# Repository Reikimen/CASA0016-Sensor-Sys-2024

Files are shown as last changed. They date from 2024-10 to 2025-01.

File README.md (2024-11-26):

---
typora-root-url: ./
---

# CASA-0016 Individual Coursework

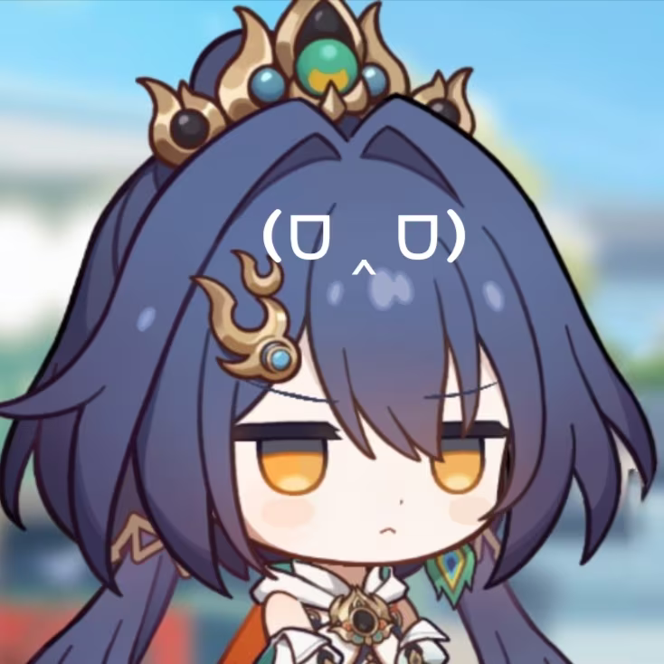
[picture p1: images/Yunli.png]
 Dankao Chen

In today's world of increasing air pollution, fresh air is no longer something to be taken for granted, but an important part of our quest for a healthy life. The completion of this project “Pure-Breath” is my personal attempt to combine technological innovation with healthy living (within module CASA-0016 ). I would like to express my special thanks to Prof. Martin for his careful guidance and valuable advice during the development process, which helped me to turn this idea into a real product.

I hope this project will not only improve the indoor air quality and living experience, but also inspire more people to become interested in the integration of technology and the environment! https://github.com/Reikimen/CASA0016-Sensor-Sys-2024

# Intro

This project designs and implements an air purification device called “Pure-Breath”. The device is based on the ESP8266 development board and provides real-time interaction, air quality monitoring, temperature and humidity display, fan control and other functions by integrating various sensors and modules. The device aims to improve indoor air quality and help users identify and respond to possible air pollution problems.

## P1 Causes of Respiratory Hypersensitiy

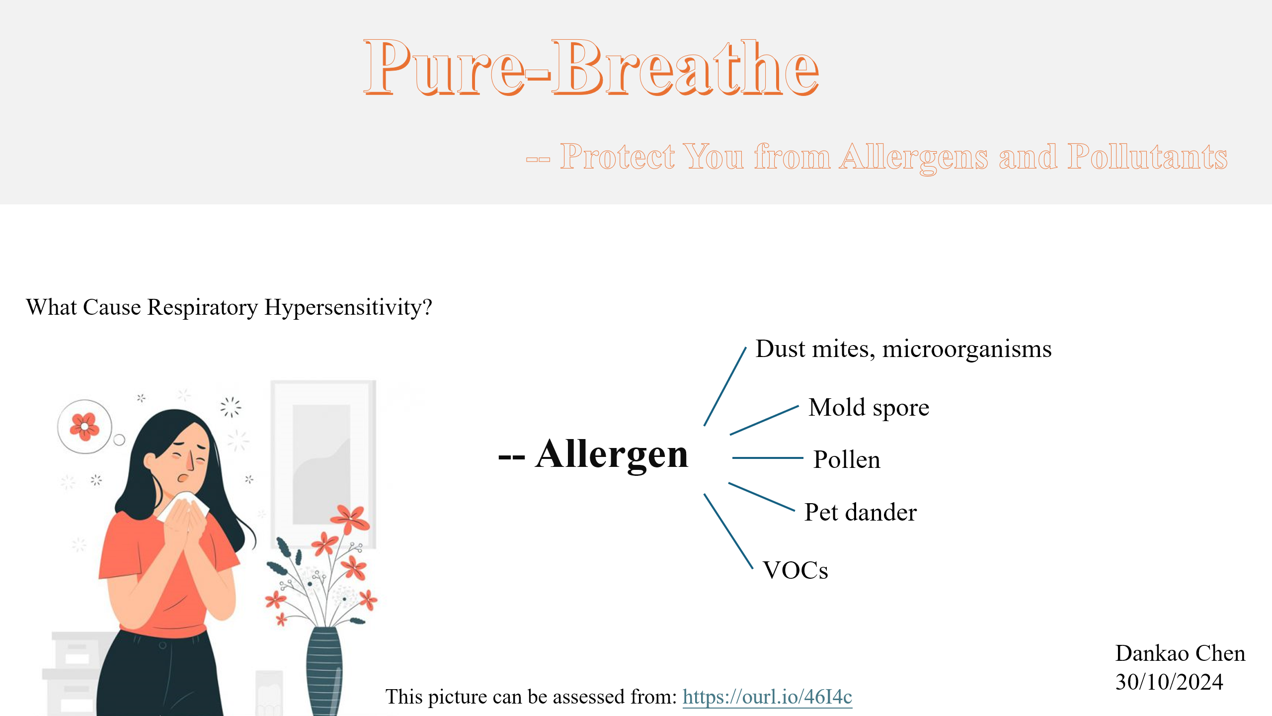
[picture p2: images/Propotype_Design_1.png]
Propotype_Design_1


## P2 Three Basic Functions of "Pure-Breath"

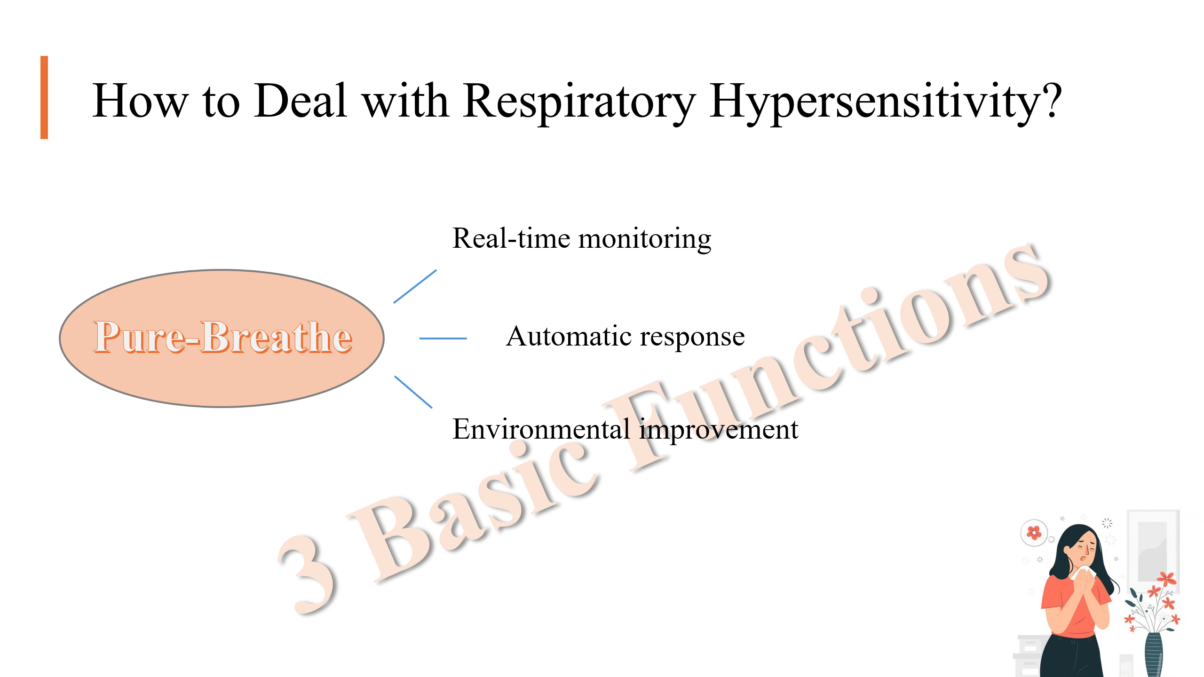
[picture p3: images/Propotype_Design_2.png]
Propotype_Design_2


## P3 The Prototype Design of "Pure-Breath"

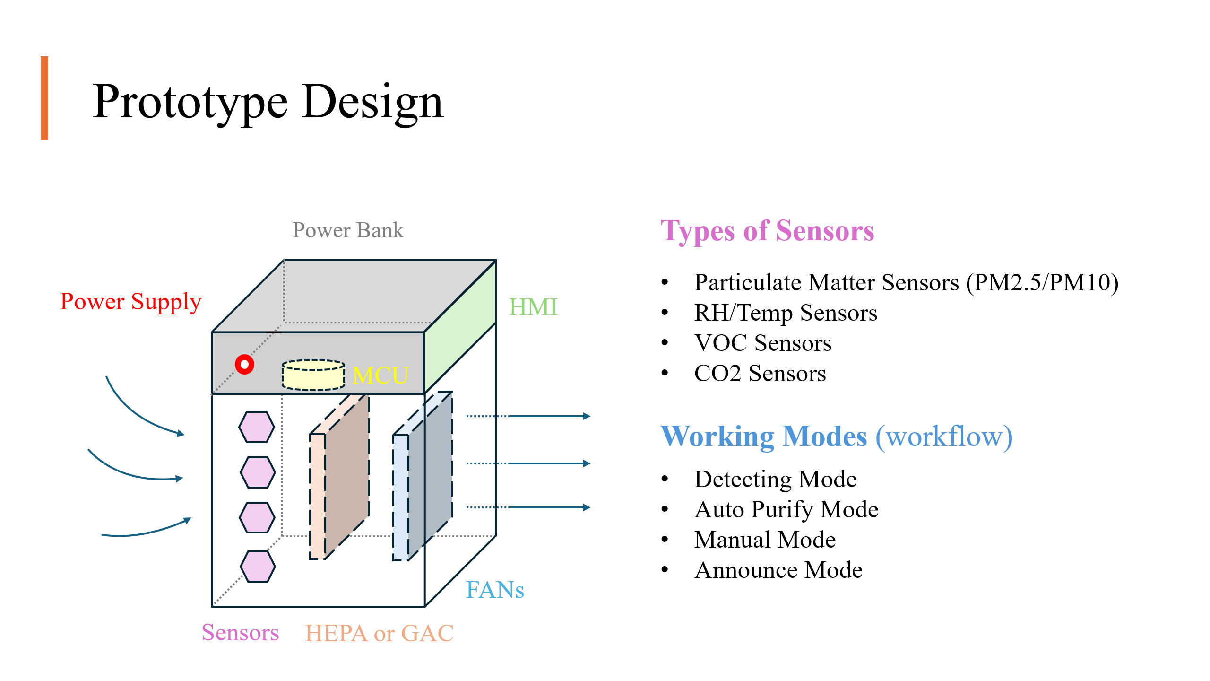
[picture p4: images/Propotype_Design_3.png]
Propotype_Design_3


However, the work flow or usage of this prototype design was not that detailed.

## P4 Product Prototype Showcase

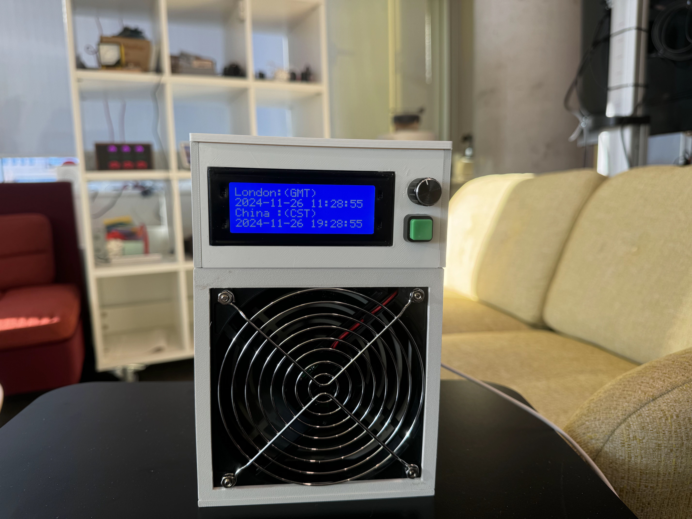
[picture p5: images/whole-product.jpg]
whole-product


<video src="/images/test.mp4" width="760" controls></video>

### Equipment features

1. **Air quality monitoring:**
   
   - Utilizes sensors (e.g. CCS811, MQ135, PMS7003) to monitor the environment in real time
   - including CO₂ concentration, TVOC value, and PM1.0, PM2.5 and PM10 particulate matter concentration.
2. **Temperature and humidity detection:**
   
   - Use SHT30 sensor to provide accurate ambient temperature and humidity data.
3. **Multi-mode fan control:**
   
   - Provides three fan modes: auto, on and off to adapt to different needs.
4. **World Time Display:**
   
   - Support synchronized display of London time and Beijing time, realized based on NTP protocol.
5. **Real-Time Interaction:**
	
	- Support 50ms interaction with users
6. **Flexible Power Supply:**
	
	- The power can be supplied both External power (e.g. Type-C) and Built-in Li-Ion battery
7. **Easy User Interaction:**
   
   - Equipped with rotary encoder and keys to support users easily and quickly switch modes and adjust settings.

### Technical characteristics

1. **Modularized design:**
   - The project is divided into several modules, including sensors, control logic, Wi-Fi connection, LCD display, etc.
   - Each module is developed independently to ensure that the system is easy to expand and maintain.
2. **Non-blocking Architecture:**
   
   - Use thread timer (RITOS method) instead of the traditional blocking delay (delay) to achieve efficient collaboration among modules.
3. **Double-buffered display:**
   
   - The use of LCD2004 screen, combined with double buffer technology, reduces I2C communication delay and improves display refresh efficiency (20HZ).
4. **High-Efficiency User Interaction:**

	- Integrates hardware (rotary encoder and buttons) and software optimization to ensure a smooth user experience without blocking system operations.

### Hardware Composition

- **Main controller chip:** ESP8266, responsible for overall logic control, Wi-Fi connection and data processing.
- **Sensors**:
  - MQ135: Monitor CO₂ concentration.
  - CCS811: Acquire eCO₂ and eTVOC data.
  - PMS7003: Detects PM particulate matter concentration.
  - SHT30: Provides ambient temperature and humidity data.
- **Display Module:** LCD2004, display sensor data and device status.
- **Power supply:** Built-in lithium battery with external power support, can be charged via Type-C or round charging port.

# For Users

Please follow the instructions below while using or maintaining the "Pure-Breath":

## Power Supply of "Pure-Breath"
“Pure-Breath” supports the following two power supply methods:

1. **External power supply**
   - Type-C connector
   - Circular charging connector

2. **Built-in Li-Ion battery**
   - The device can run for about 30 minutes without external power supply.
   - The built-in lithium battery is automatically charged when an external power source is connected. For faster charging, you can turn off the device and charge the battery only.

> **Hint**: One way to increase the battery life of your device is to increase the capacity of the Li-Ion battery, which gives the user a longer battery life experience. (Just like Apple earns high storage space costs by soldering SSDs, just kidding)

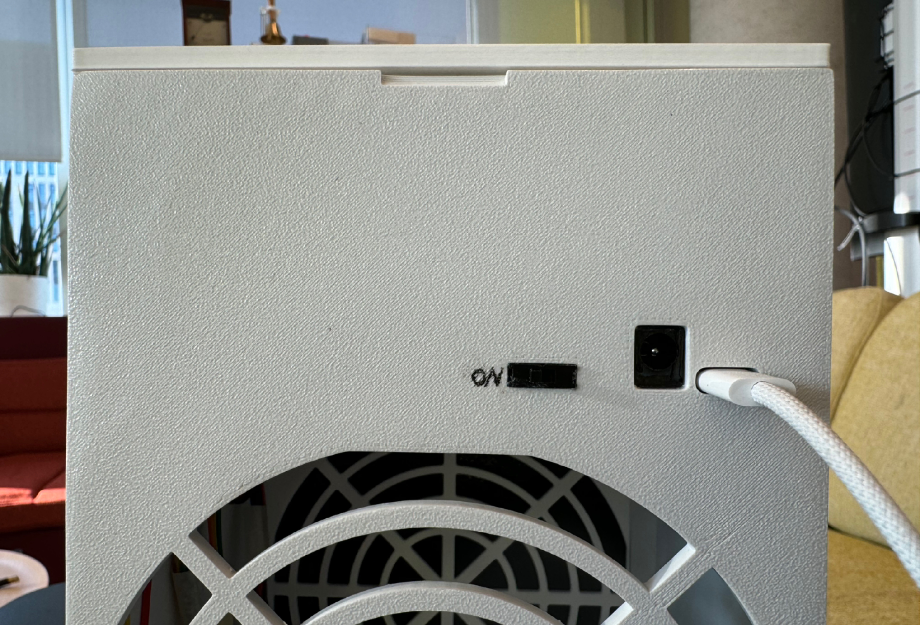
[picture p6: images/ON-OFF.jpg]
ON-OFF


## Get Start with "Pure-Breath"

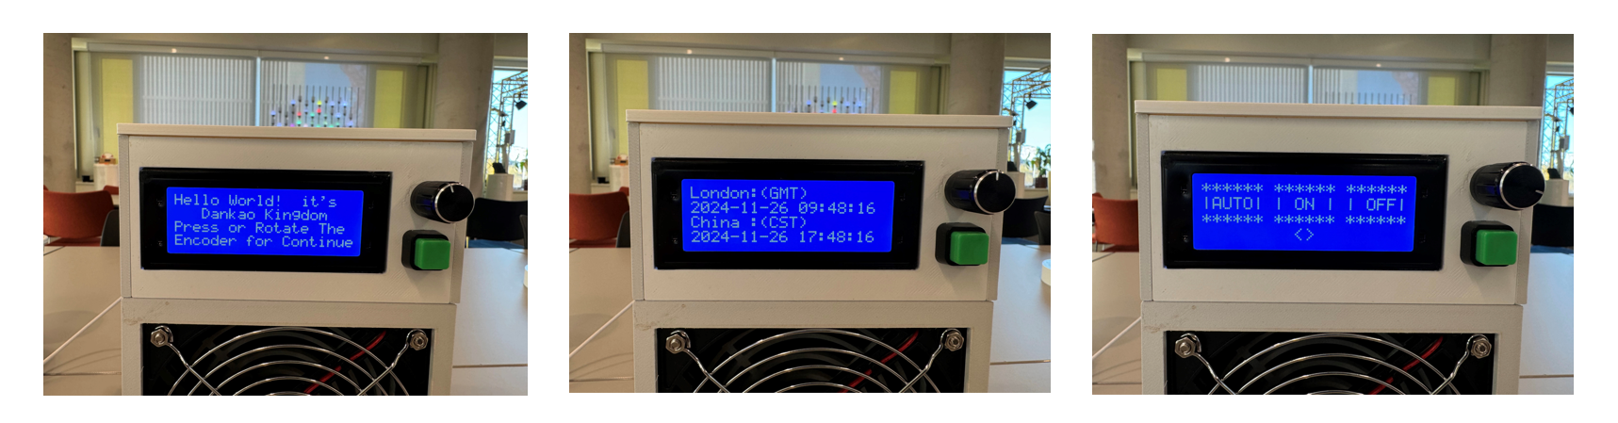
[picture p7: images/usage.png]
usage


1. **Starting the device** 
   
	- Slide the switch on the back of the unit to the **"ON"** position. 
  
2. **Start-up process**
   - The LCD screen will briefly display a blue screen for about 10 seconds. 
	
   - During the blue screen, the device connects to Wi-Fi (**CE-Hub-Students**) and synchronizes with world time. 
	
	- Upon successful connection, the LCD will display a welcome screen and prompt the user to rotate or press the rotary encoder to turn it on. 

3. **Main interface and mode selection** 
   Upon startup, you will enter the main user interaction interface with a total of **5 modes** to choose from: 
   - **TIME (London time and Beijing time)** 
   - **T&RH (Temperature and Humidity)**
   - **PM (PM1.0, PM2.5 & PM10)** 
   - **AQI (Air Quality Index)**
- **FAN (Fan Mode, Auto, On and Off)** 
  
   **Selection Mode Method**: 
   - Move the pointer to the desired mode by rotating the encoder. 
   - Press the encoder to confirm the selection. 
   
	**Example**: 
	- By selecting the **"TIME"** mode and pressing the encoder, the LCD will display London time and Beijing time. 
	- To exit the current mode, press the green square button to return to the main screen. 

4. **Special operations in FAN mode** 
   **"FAN ’** mode contains **3 sub-modes**: 
   
    - **AUTO** 
    - **ON** 
	- **OFF** 
   
   **Selection of sub-mode method**: 
   
   - Rotate the encoder to point the pointer to the desired sub-mode, then press the green square button to return to the main screen without additional confirmation. 

## Replacing the carbon fiber filter

After the equipment runs for a long time, the carbon fiber filter will inevitably accumulate a lot of dust, so it is extremely important to replace the filter regularly. 

**To replace the air filter, Please follow the following steps:**

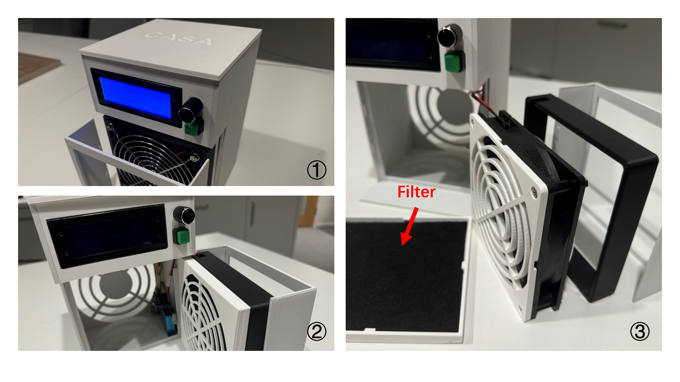
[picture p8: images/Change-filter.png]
Change-filter


> **Very important !!! **

> **Switch off the unit before replacing the filter, do not operate with electricity !!!! **

## Other Precautions

In a clean environment (e.g. laboratory) the PM sensor may show ‘0’, this is normal as there is less particulate matter in the environment. To test the sensor, try the following: 

- Tear a paper towel near the air intake.
- Sprinkle some dust around the unit.

This simulates particulate matter and makes it easier to see how the PM sensor reading changes.

# For Developers

## Repo Structure

```plaintext
- Sensor-Sys/
            - Air_Purify_Sys/
                        - Air_Purify_Sys.ino
                        - MyActuator.h
                        - MyConfig.h
                        - MyCtrlLogic.h
                        - MySensors.h
                        - MyWifi.h
            - Components/
                        - ccs811basic/...
                        - DHT22/...
                        - EasyBtn/...
                        - ESP8266_GetTime/...
                        - I2C_address_search/...
                        - LCD2004/...
                        - ...
            - Datasheets/
                        - EC11-1370808.pdf
                        - SNS-MQ135.pdf
                        - ...
            - images/
                        - Yunli.png
                        - ESP8266-Pins.png
                        - ...
            - README.md
```

The repo contains the following components:
- Air_Purify_Sys/
  - The main program folder, opened with an Arduino and burned into the ESP8266
- Components/
  - Components folder, which contains how to use each component, some of the improved non-blocking runtime programs, and programs for checking circuit connections (e.g., items for checking the connection of I2C devices: I2C_address_search)
- Datasheets/
  - Datasheets for some of the components on which the non-blocking functions of the sensors can be edited.
- images/
  - For storing images in the README
- README.md

## Main program folder - Air_Purify_Sys/
Here is an overview of what each file in the main program does:
### MyConfig.h
- Contains the system configuration and global variable definitions:
  - Define thread timer periods (e.g., periods for Wi-Fi, sensor, display updates).
  - Configure Wi-Fi parameters (SSID and password) and NTP parameters (time zone).
  - Configure sensor and actuator interfaces (e.g., MQ135, CCS811, PMS7003, LCD2004).
  - Configure pins for user interaction (e.g. Encoder and Home Button)
- Provide hardware-related initialization settings:
  - De-jitter time constants for knobs and buttons.
  - Pin mapping and initialization for fans and displays.

### MyCtrlLogic.h
- Implemented control logic:
  - Operation logic based on knob rotation, button press, and Home button.
  - Defines `DISPLAYMODE` state switching rules to control the device's mode of operation.
- Provides input processing threads:
  - Implement knob direction detection (left/right rotation).
  - De-jitter detection of button state change.
  - Real-time response mechanism to user input.

### MySensors.h
- Realizes data reading and processing of various sensors:
  - **MQ135**: Get CO₂ concentration by the calculation formula provided in the datasheet.
  - **CCS811**: Get eCO₂ and eTVOC data, support initialization and error handling.
  - **PMS7003**: Non-blocking reading of particulate matter concentration data, supports frame parsing and calibration.
  - **SHT30**: non-blocking reading of temperature and humidity, supports frame parsing and checksum.
- Provides sensor-specific threads:
  - Ensures that each sensor's data is updated regularly without blocking the rest of the system.

### MyWifi.h

- Implement Wi-Fi connection and time synchronization functions:
  - Wi-Fi connection status checking and reconnection mechanism.
  - NTP time synchronization function to get time in London and China.
- Provide `WorldTimerThread` thread:
  - Periodic output of date and time in current time zone.

### MyActuator.h
- Involves LCD display and fan control:
  - **LCD display**: implements double buffering mechanism to reduce I2C communication time and improve display refresh efficiency (20 Hz).
  - **FAN CONTROL**: set the fan operating mode (auto, on or off) based on `DISPLAYMODE`.
- Defines the content logic of the display mode:
  - Generate display content based on `DISPLAYMODE`, e.g. time, sensor data, air quality.

### Air_Purify_Sys.ino
- Main program file, integrates modules and coordinates system operation:
  - Initialize all modules (Wi-Fi, sensors, control logic, display, etc.).
  - Defines the main loop and schedules the threads to run.
  - May include system error handling and overall state management.

### Collaboration between files
- Modules share state through global variables (e.g. `DISPLAYMODE`, timers).
- Each module is independently responsible for a specific function. The overall design ensures a high degree of modularity and extensibility.

## Version Control

All the version control is based on the GitHub, new branch (or say version) are created after some significant features were add to the Project.

Here is part of the Commits Histories for one of the history branch: **v0.6**

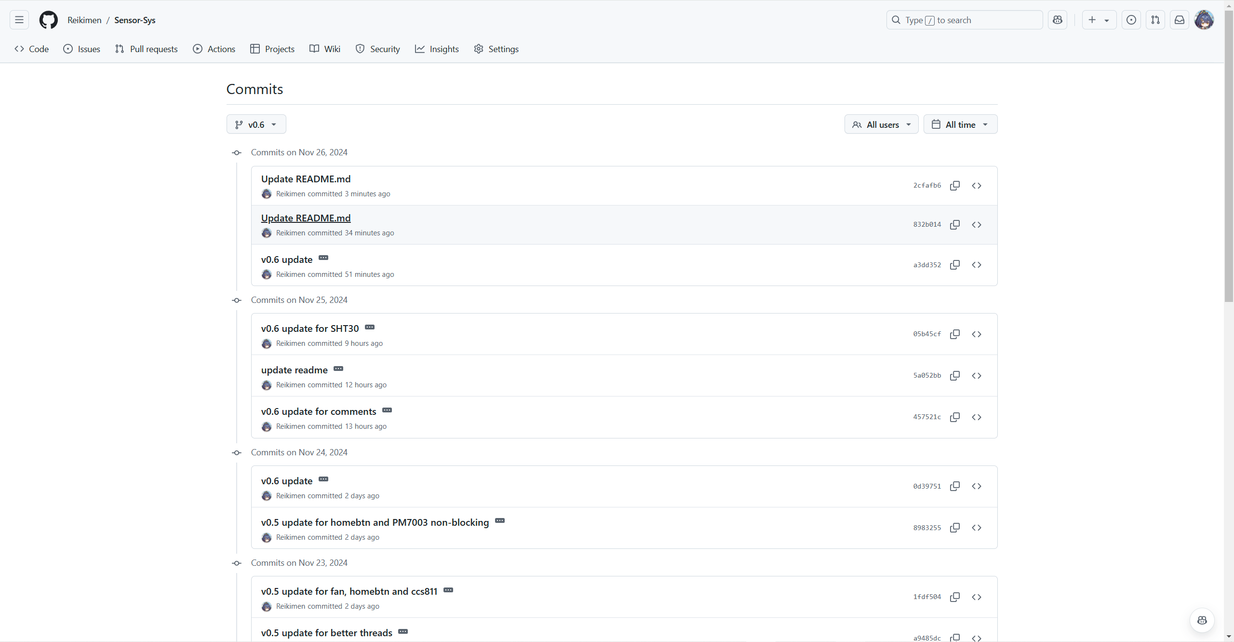
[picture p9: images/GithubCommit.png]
GithubCommit


## Pin Diagram & Allocation

### Pin Diagram
Here is the Pin Diagram of ESP8266:

<div align="center">
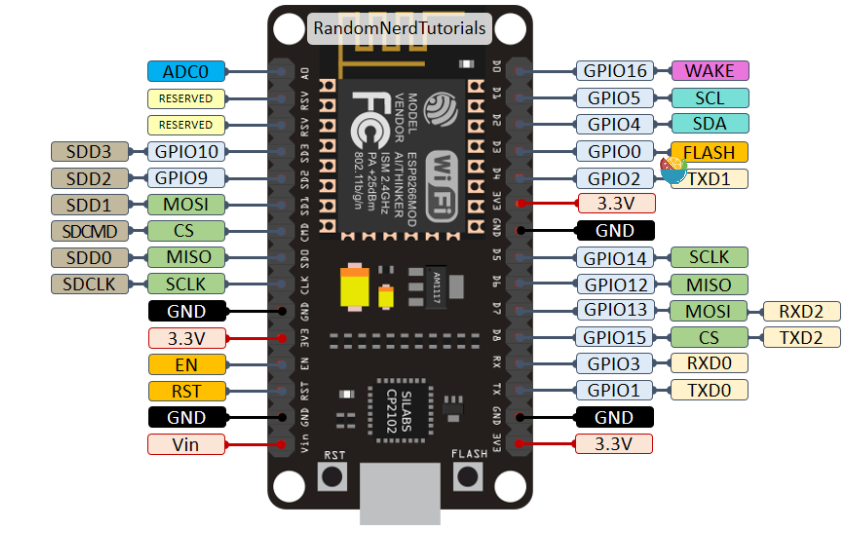
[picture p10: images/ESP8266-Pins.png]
    
</div>

### Pin Allocation

Here is a table of commonly used pin assignments for ESP8266 development boards (such as NodeMCU or similar), including their functions, GPIO numbers, and key considerations:

| Pin No. | GPIO | Default Function | Project Usage | Common Usage | Notes |
|---|---|---|---|---|---|
| D0 | GPIO 16 | Deep Sleep Wake-Up | NMOS (Fan) (TBD) | General IO, Low-Frequency Signal | No PWM, I2C, or interrupt support; only supports digital input/output. |
| D1 | GPIO 5 | I2C (SCL) | I2C (SCL) CCS811 | General IO, I2C Clock Signal  | Versatile IO, compatible with most functions. |
| D2 | GPIO 4 | I2C (SDA) | I2C (SDA) CCS811 | General IO, I2C Data Signal | Versatile IO, compatible with most functions. |
| D3 | GPIO 0 | Boot Mode Control, Flash Button | CCS811 | General IO (Low Current) | Must stay HIGH during power-up; otherwise, enters programming mode. Avoid high-frequency or heavy loads. |
| D4 | GPIO 2 | Built-in LED, UART1 TX  | Serial1 Debug | General IO, LED Control | HIGH at power-up; use as output only to avoid false resets or boot issues. |
| D5 | GPIO 14 | SPI (SCLK) | Encoder Button | General IO, SPI Clock Signal | Suitable for high-speed signals. |
| D6 | GPIO 12 | SPI (MISO) | Encoder Pin A | General IO, SPI Data Input | Suitable for high-speed signals. |
| D7 | GPIO 13 | SPI (MOSI) | Encoder Pin B | General IO, SPI Data Output | Suitable for high-speed signals. |
| D8 | GPIO 15 | SPI (CS) | Home Button (Pull-down Resistor Included) | General IO, SPI Chip Select Signal | Must stay LOW during power-up; not suitable for signals requiring sustained HIGH levels. |
| RX | GPIO 3 | UART0 RX | UART RX PMS7003 | Serial Communication (Receiving Data) | Default USB UART connection for debugging; can be used as input, but conflicts with debugging. |
| TX | GPIO 1 | UART0 TX | UART TX PMS7003 | Serial Communication (Sending Data) | Default USB UART connection for debugging; can be used as output, but conflicts with debugging. |
| A0 | ADC0 | Analog Input (0~1V) | MQ135 (A0) | Reading Analog Signals (Sensors) | Voltage range limited to 0~1V; requires voltage divider or amplifier for higher voltages. |

**Notes:**
- Ensure proper GPIO configuration to avoid boot or operational conflicts.

- Consider power-up states and default behaviors when selecting pins for specific tasks.

- Use external resistors or components as necessary to adjust voltage levels or signal characteristics.

## Circuit and Modeling

### Schematic Diagram of the prototype:

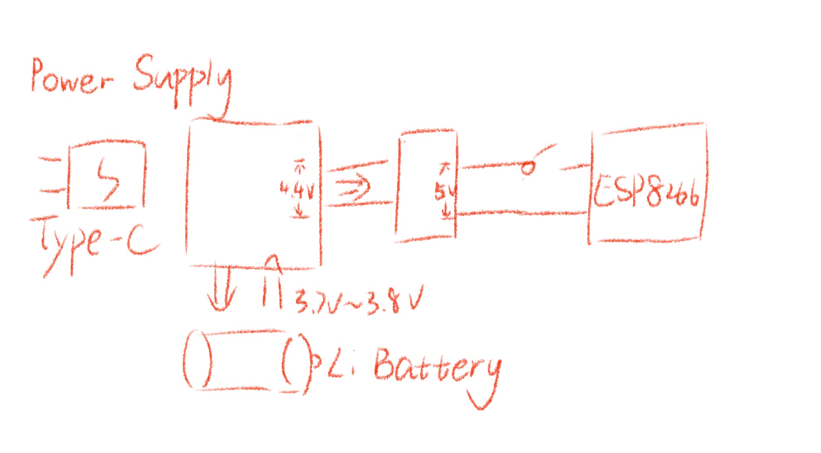
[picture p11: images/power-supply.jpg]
power-supply


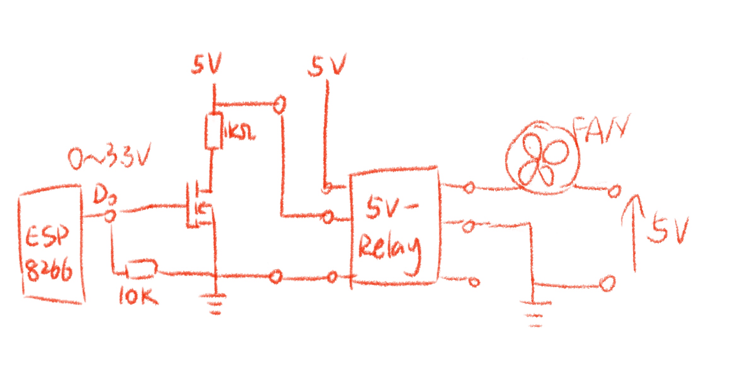
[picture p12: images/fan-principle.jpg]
fan-principle


### Appearance Design of the prototype:

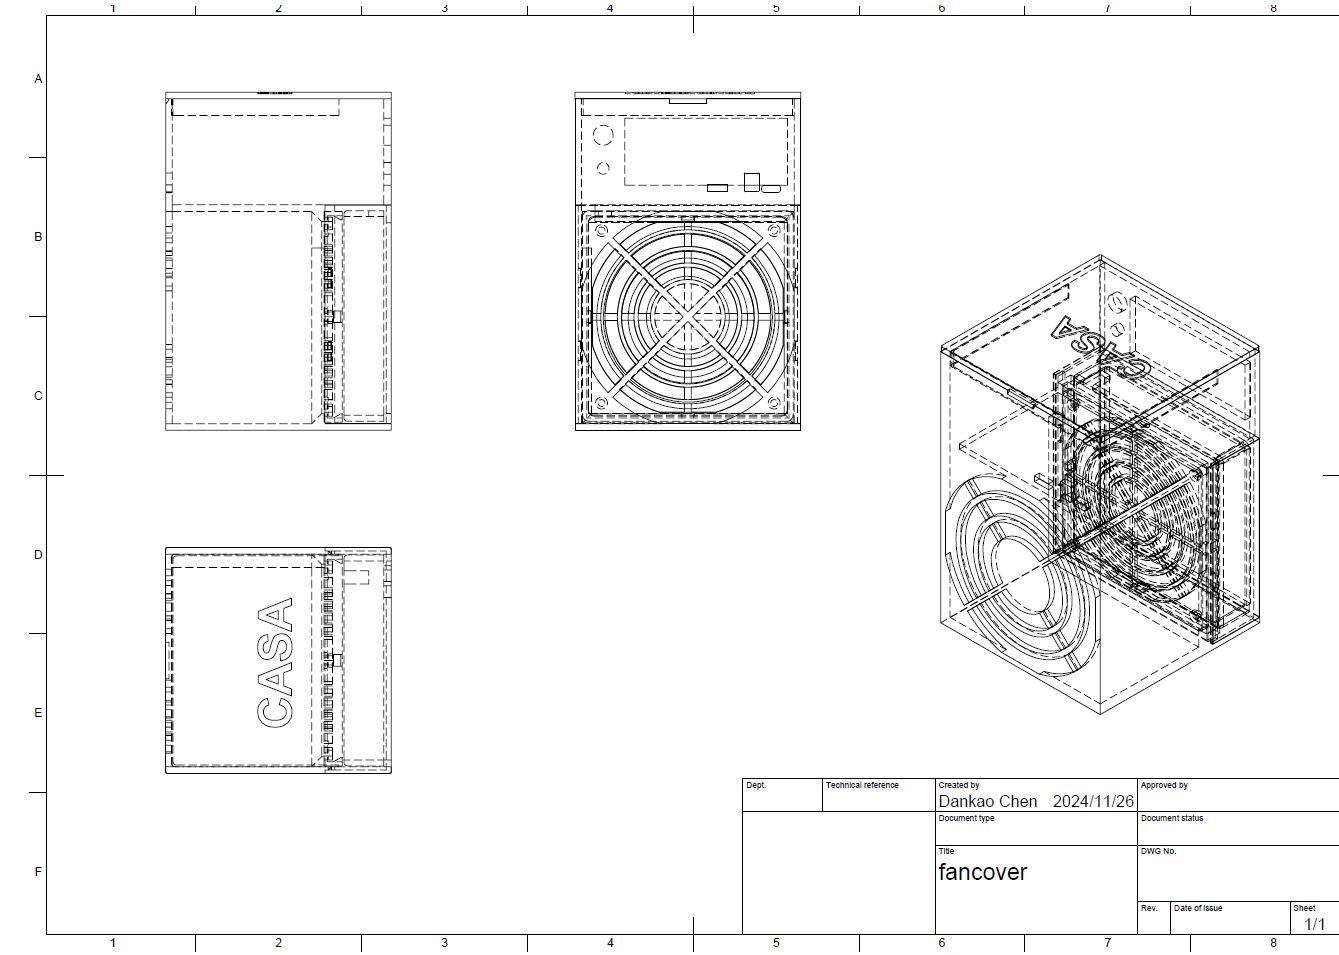
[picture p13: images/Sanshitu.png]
Sanshitu


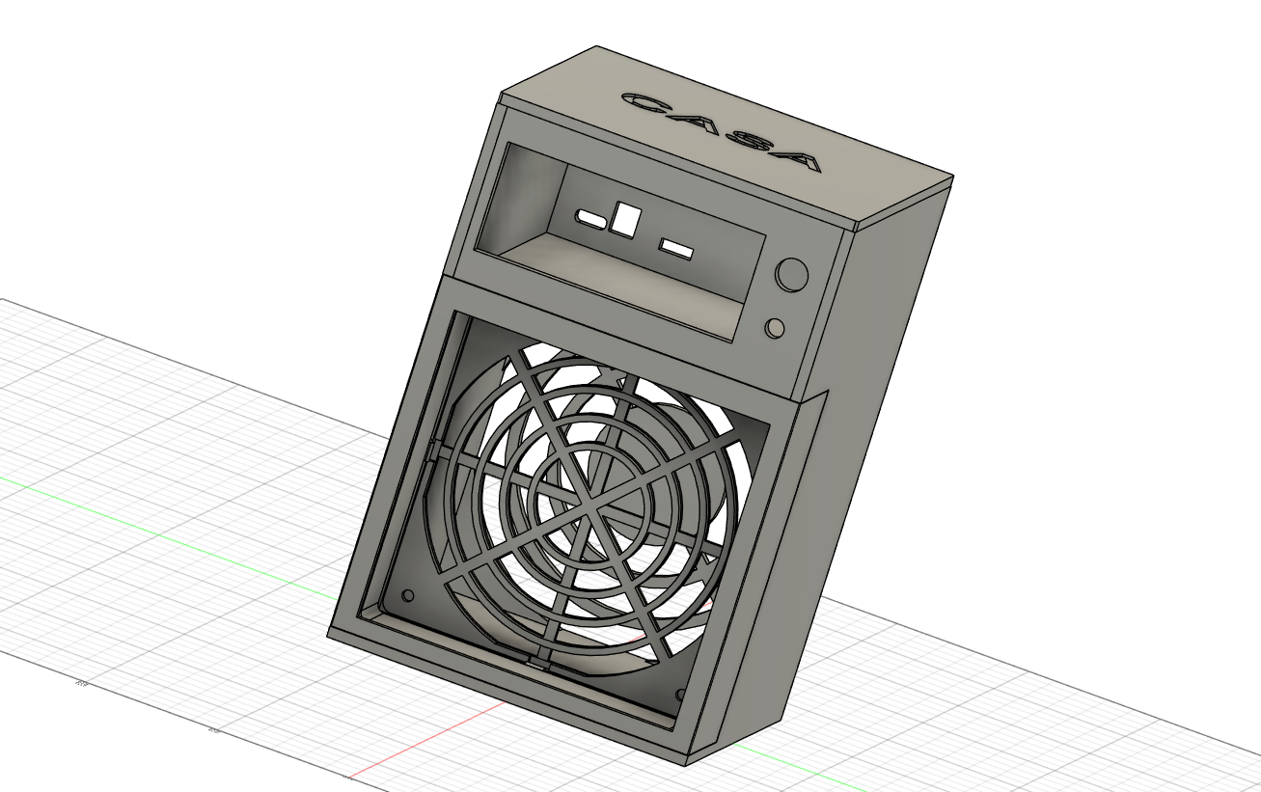
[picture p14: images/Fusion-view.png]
Fusion-view


### Internal Structure of the prototype:

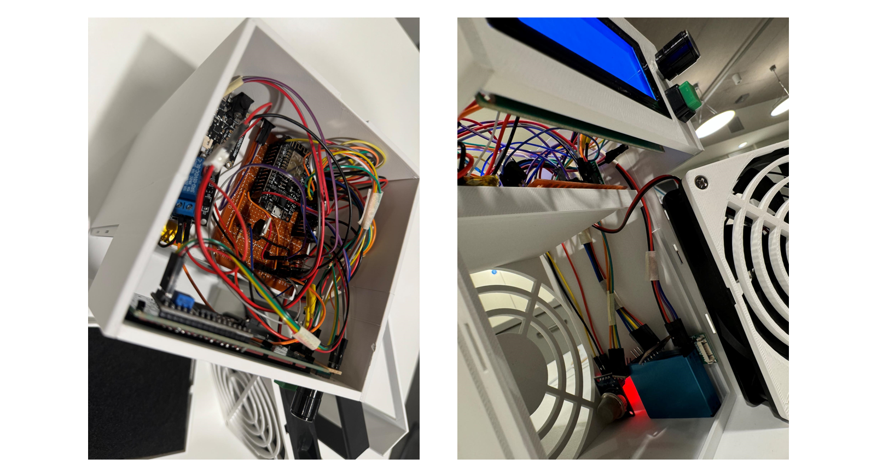
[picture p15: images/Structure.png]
Structure


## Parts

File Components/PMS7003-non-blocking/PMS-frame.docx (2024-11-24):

PMS7003 数据帧协议

根据 PMS7003 官方文档或常见的通信协议，PMS7003 通过 UART（串口）以固定格式发送数据帧。典型帧结构如下：

字节序号 (Byte Index) | 字节含义 | 数据说明
0 | 帧头 1 (0x42) | 固定值，表示数据帧开始
1 | 帧头 2 (0x4D) | 固定值，表示数据帧开始
2-3 | 数据帧长度 | 数据帧后续字节数（不含帧头）
4-5 | PM1.0 标准颗粒物浓度 | 以微克每立方米 (ug/m³) 为单位
6-7 | PM2.5 标准颗粒物浓度 | 以微克每立方米 (ug/m³) 为单位
8-9 | PM10 标准颗粒物浓度 | 以微克每立方米 (ug/m³) 为单位
... | ... | 其他数据字段
N-2, N-1 | 校验和 (Checksum) | 数据帧的校验和

帧头的来源

1. 帧头定义：
  - PMS7003 使用帧头 0x42 和 0x4D 作为数据帧的起始标志。
  - 其中，0x42 是 ASCII 字符 B，0x4D 是 ASCII 字符 M，可能表示 "Byte" 和 "Message" 或与 Plantower 厂商定义有关。
2. 固定值：
  - 帧头在所有通信中是固定的，用于标识数据帧的开始，以便主机设备能够同步并解析有效数据。
  - 无论传感器是否工作在主动模式（主动发送数据）还是被动模式（主机请求后发送数据），帧头保持一致。

帧头在解析中的作用

帧头的固定值提供以下功能：

1. 数据同步：
  - 通过匹配帧头，主机可以判断是否接收到有效的开始数据帧。
  - 如果在数据流中发现帧头，缓冲区可以从帧头开始解析，避免错误解码。
2. 通信可靠性：
  - 帧头有助于过滤噪声数据或错误数据。
  - 例如，接收到的数据如果不以 0x42, 0x4D 开头，则可以直接丢弃，避免错误解码。
3. 协议标准化：
  - 0x42 和 0x4D 是 PMS 系列（如 PMS5003、PMS7003）传感器的协议标准。其他 Plantower 系列传感器也采用类似协议。

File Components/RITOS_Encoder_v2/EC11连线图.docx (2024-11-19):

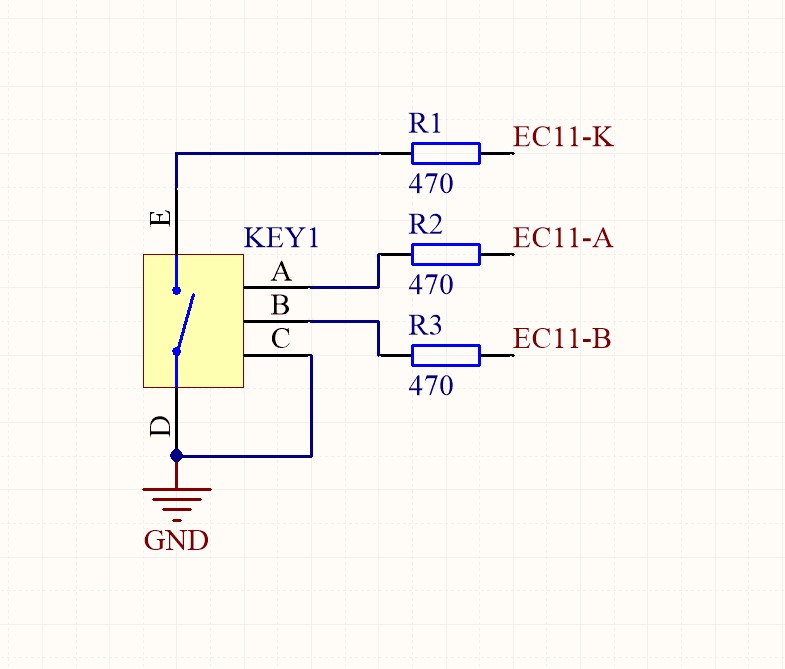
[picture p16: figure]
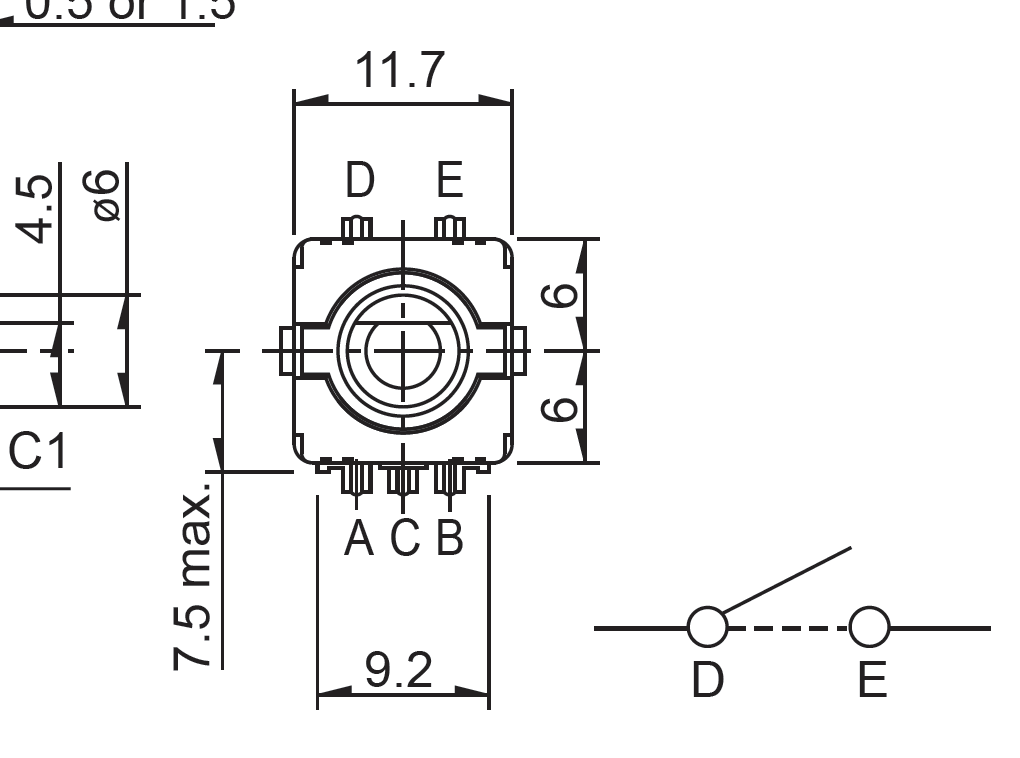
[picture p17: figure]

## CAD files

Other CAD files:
Structure_Design/Pure-Breath-v29.f3d

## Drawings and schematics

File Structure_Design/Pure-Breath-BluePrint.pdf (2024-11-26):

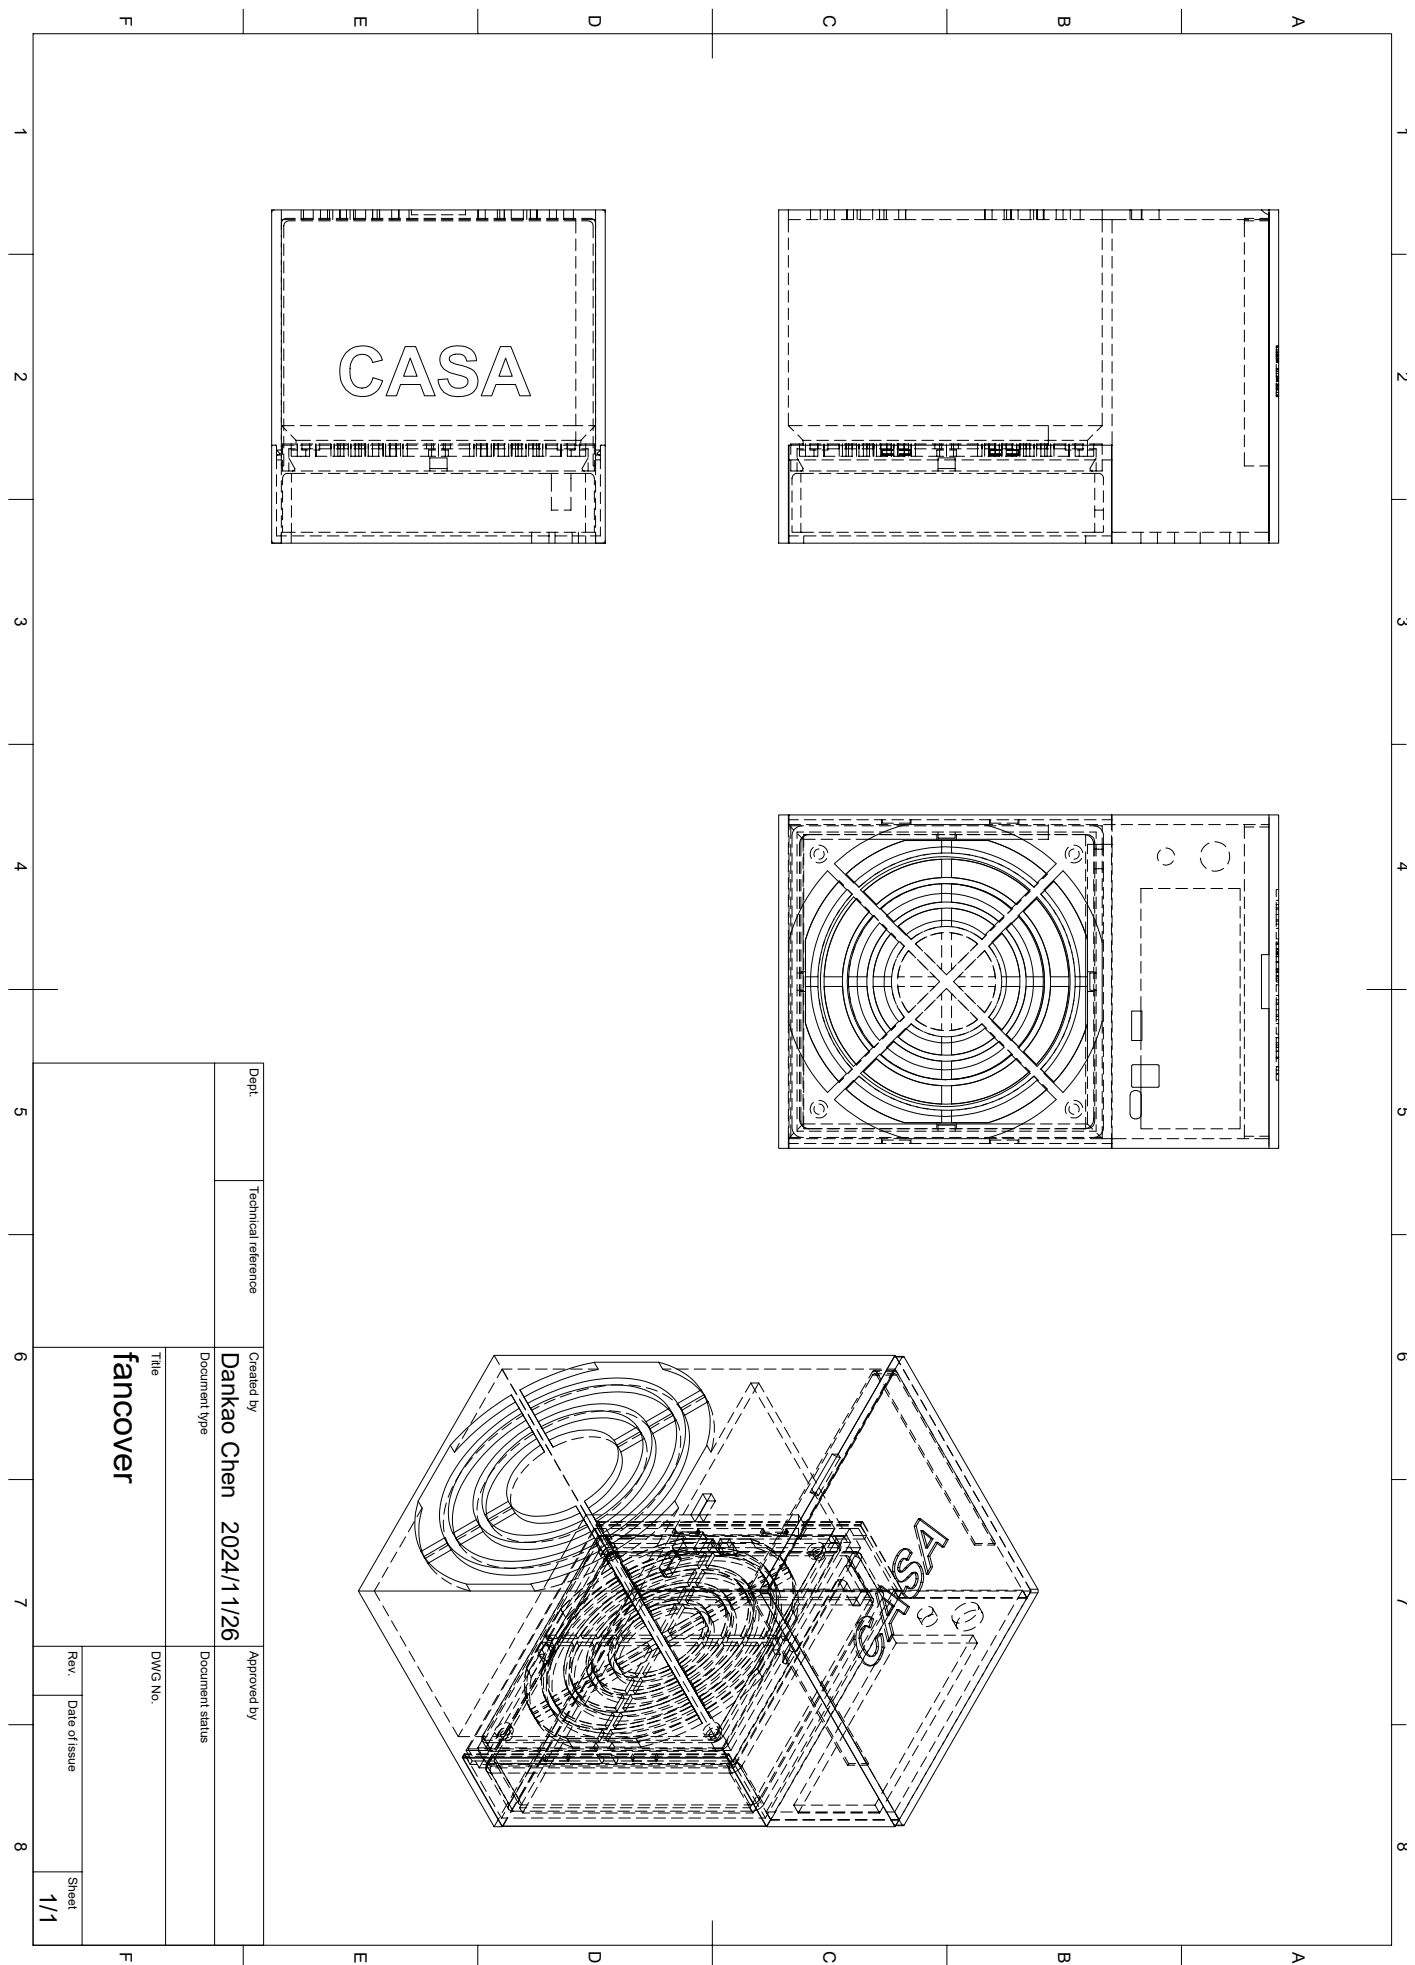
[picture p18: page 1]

1 A 2 3 4 5 6 7 8 1 2 3 4 5 6 7 8 FEDCB FEDCBA Dept. Technical reference Created by Approved by Title DWG No. Document type Document status Rev. Date of issue Sheet 2024/11/26 1/1 fancover Dankao Chen

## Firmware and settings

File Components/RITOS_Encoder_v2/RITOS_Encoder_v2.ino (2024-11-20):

#define encoderPinA 12  // D6
#define encoderPinB 13  // D7
#define encoderBtn 14   // D5

#include "ritos.h" // https://github.com/0ingchun/RITOS-lib-Arduino

volatile int encoderPosition = 0;   // 保存旋转计数
volatile bool buttonPressed = false;  // 按钮按下状态

// 线程任务声明
Ritos taskEncoder;
Ritos taskCheckEncoder;
Ritos taskButton;

// 去抖动时间
#define DEBOUNCE_TIME 50  
unsigned long lastDebounceTime = 0;

// 编码器状态
int lastEncoderStateA = LOW;
int lastEncoderStateB = LOW;

// 按钮状态
int lastButtonState = HIGH;

int encodercount = 10;
int buttoncount = 10;

void encoderThread() {

  int currentStateA = digitalRead(encoderPinA);
  int currentStateB = digitalRead(encoderPinB);

  // 检测到旋转
  if (lastEncoderStateA == LOW && currentStateA == HIGH) {
    if (currentStateB == LOW) {
      encoderPosition--;  // 左旋
      //Serial.println("Rotated Left");
    } else {
      encoderPosition++;  // 右旋
      //Serial.println("Rotated Right");
    }
  }

  // 更新状态
  lastEncoderStateA = currentStateA;
  lastEncoderStateB = currentStateB;
}

void checkencoderThread(){
  encodercount--;
  if (encodercount<=0){
    encodercount = 10;
    if (encoderPosition < 0){
      Serial.println("Rotated Left");
    }
    // else if (encoderPosition == 0) {
    //   Serial.println("");
    // }
    // else {
    //   Serial.println("Rotated Right");
    // }
    if (encoderPosition > 0){
      Serial.println("Rotated Right");
    }

    // 重归 encoderPosition 为 0
    encoderPosition = 0;
  }
}

void buttonThread() {
  int currentButtonState = digitalRead(encoderBtn);

  // 去抖检测
  if (currentButtonState != lastButtonState) {
    lastDebounceTime = millis();
  }

  if ((millis() - lastDebounceTime) > DEBOUNCE_TIME) {
    // 按钮状态变化检测
    if (currentButtonState == LOW && !buttonPressed) {
      buttonPressed = true;
      Serial.println("Button Pressed");
    } else if (currentButtonState == HIGH && buttonPressed) {
      buttonPressed = false;
      Serial.println("Button Released");
    }
  }

  // 更新按钮状态
  lastButtonState = currentButtonState;
}

void setup() {
  Serial.begin(115200);

  // 初始化引脚
  pinMode(encoderPinA, INPUT_PULLUP);
  pinMode(encoderPinB, INPUT_PULLUP);
  pinMode(encoderBtn, INPUT_PULLUP);

  // 创建线程
  taskEncoder.task(encoderThread);
  taskCheckEncoder.task(checkencoderThread);
  taskButton.task(buttonThread);
}

void loop() {
  // 空，所有逻辑在线程中执行
}

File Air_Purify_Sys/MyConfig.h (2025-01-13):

#include <Arduino.h>
#include <Wire.h>
#include <ESP8266WiFi.h>
#include <ezTime.h>
#include <LiquidCrystal_I2C.h>
#include "MQ135.h"
#include "ccs811.h"  // CCS811 library
// #include "PMS.h" // Don't need it anymore, for the fuctions insides has delay or sleep that would block the whole sys
#include "ritos.h" // https://github.com/0ingchun/RITOS-lib-Arduino

//////////////////////////////////////////////////////// Threads Time ///////////////////////////////////////////////////////
// Change the values here to modify the frequency for every threads, except the 1kHz threads
/* Wifi */
const int CONSTTIMECOUNT = 1000; 
int timecounter = CONSTTIMECOUNT; // WorldTimerThread

/* Actuator */
const int CONSTLCDCOUNT = 50; 
const int CONSTFANCOUNT = 50; 
int LCDcount = CONSTLCDCOUNT;
int Fancount = CONSTFANCOUNT;

/* Ctrl */
const int CONSTENCODERCOUNT = 10;  // Used to increase the period for detecting the rotary encoder to enable runtime support for modeLogic
int encodercount = CONSTENCODERCOUNT;

/* Sensor */
const int CONSTMQ135COUNT = 2000; 
int MQ135count = CONSTMQ135COUNT;

const int CONSTPMS7003COUNT = 10000;
int PMS7003count = CONSTPMS7003COUNT;

const int CONSTSHT30COUNT = 2000;
int sht30count = CONSTSHT30COUNT;

//////////////////////////////////////////////////////// Wi-Fi ///////////////////////////////////////////////////////
// Wi-Fi info
// inside secrets.h

// Create a time zone object
Timezone londonTZ;
Timezone chinaTZ;

String londonST;
String londonDate;
String londonTime;
String chinaST;
String chinaDate;
String chinaTime;

//////////////////////////////////////////////////////// Actuator ///////////////////////////////////////////////////////
// LCD2004
LiquidCrystal_I2C lcd(0x27, 20, 4); // VDD to 5V, GND to GND, SDA to D2, SCL to D1

int DISPLAYMODE = 0;

char buffer[4][21]; // 4 lines of up to 20 characters each for storage of the current display

// Fan & NMOS
// #define FanPin    2    // D4
#define FanPin    16    // D0

// The fan modes are classified according to DISPLAYMODE, Auto: 10, On: 11, Off: 12.
// The corresponding FANMODE is Auto: 0, On: 1, Off: 2.
int FANMODE = 0;

/////////////////////////////////////////////////////// Ctrl IO ////////////////////////////////////////////////////////
#define encoderPinA     12    // D6
#define encoderPinB     13    // D7
#define encoderPinBtn   14    // D5
#define homeBtnPin      15    // D8

// De-jitter time
#define DEBOUNCE_TIME 30  // Used for both encoderBtn (Simplified as 'Button') and homeBtn
unsigned long ButtonlastDebounceTime = 0;
unsigned long homeBtnlastDebounceTime = 0;

// Save rotation count, button press state
volatile int encoderPosition = 0;
volatile bool buttonPressed = false;
volatile bool homebuttonPressed = false;

// The state of encoder pins, use HIGH to avoid the first detceting turn
int lastEncoderStateA = HIGH;
int lastEncoderStateB = HIGH;

// Counterclockwise (left) is 1, Clockwise (right) is 0, default is 11451
int EncoderRotate = 11451;

// Button status, default null pin high
int lastButtonState = HIGH;
int homelastButtonState = HIGH;

/////////////////////////////////////////////////////// Sensors ////////////////////////////////////////////////////////
// MQ135

MQ135 SensorMQ135 = MQ135(A0); // Sensor connected to pin A0

float co2_ppm = 114514;
float rzero = 440;
float rs = 11451;

// ccs811
// Wiring for ESP8266 NodeMCU boards: VDD to 3V3, GND to GND, SDA to D2, SCL to D1, nWAKE to D3 (or GND)
CCS811 ccs811(0); // nWAKE on D3

const int CONSTCCS811COUNT = 1000;
int ccs811count = CONSTCCS811COUNT;

uint16_t eco2, etvoc, errstat, raw;

// PMS7003
#define FRAME_LENGTH 32  // PMS7003 data frame length
#define FRAME_START_1 0x42
#define FRAME_START_2 0x4D

uint8_t pmsbuffer[FRAME_LENGTH];  // Data buffer
uint8_t bufferIndex = 0;          // Buffer index
bool frameReady = false;          // Flag bit indicating if a full frame is available

struct PMSData {
  uint16_t pm1_0;
  uint16_t pm2_5;
  uint16_t pm10_0;
};

PMSData pmsData;

// SHT30传感器的I2C地址
#define Addr_SHT30 0x44

// 存储SHT30测量数据的变量
uint8_t sht30_data[6];
float sht30_cTemp;     // 摄氏温度
float sht30_fTemp;     // 华氏温度
float sht30_humidity;  // 相对湿度

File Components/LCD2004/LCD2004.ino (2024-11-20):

#include <Wire.h>

#include <LiquidCrystal_I2C.h>

LiquidCrystal_I2C lcd(0x27, 20, 4);


void setup(){

  lcd.init();
  lcd.backlight();

  lcd.setCursor(0, 0);lcd.print("Hello Dankao!");
  lcd.setCursor(0, 1);lcd.print("Only serve in");
  lcd.setCursor(0, 2);lcd.print("  Dankao Kingdom");
  lcd.setCursor(0, 3);lcd.print("");

}

void loop()

{
  lcd.setCursor(0, 0);lcd.print("****** ****** ******");
  lcd.setCursor(0, 1);lcd.print("|TIME| |T&RH| | PM |");
  lcd.setCursor(0, 2);lcd.print("****** ****** ******");
  lcd.setCursor(0, 3);lcd.print("  <>                ");
  delay(1500);

  lcd.setCursor(0, 0);lcd.print("****** ****** ******");
  lcd.setCursor(0, 1);lcd.print("|TIME| |T&RH| | PM |");
  lcd.setCursor(0, 2);lcd.print("****** ****** ******");
  lcd.setCursor(0, 3);lcd.print("         <>         ");
  delay(1500);

  lcd.setCursor(0, 0);lcd.print("****** ****** ******");
  lcd.setCursor(0, 1);lcd.print("|TIME| |T&RH| | PM |");
  lcd.setCursor(0, 2);lcd.print("****** ****** ******");
  lcd.setCursor(0, 3);lcd.print("                <>  ");
  delay(1500);

  lcd.setCursor(0, 0);lcd.print("****** ****** ******");
  lcd.setCursor(0, 1);lcd.print("|T&RH| | PM | | CO2|");
  lcd.setCursor(0, 2);lcd.print("****** ****** ******");
  lcd.setCursor(0, 3);lcd.print("                <>  ");
  delay(1500);

  lcd.setCursor(0, 0);lcd.print("****** ****** ******");
  lcd.setCursor(0, 1);lcd.print("| PM | | CO2| |FANs|");
  lcd.setCursor(0, 2);lcd.print("****** ****** ******");
  lcd.setCursor(0, 3);lcd.print("                <>  ");
  delay(1500);

  lcd.setCursor(0, 0);lcd.print("****** ****** ******");
  lcd.setCursor(0, 1);lcd.print("| PM | | CO2| |FANs|");
  lcd.setCursor(0, 2);lcd.print("****** ****** ******");
  lcd.setCursor(0, 3);lcd.print("         <>         ");
  delay(1500);

  lcd.setCursor(0, 0);lcd.print("****** ****** ******");
  lcd.setCursor(0, 1);lcd.print("| PM | | CO2| |FANs|");
  lcd.setCursor(0, 2);lcd.print("****** ****** ******");
  lcd.setCursor(0, 3);lcd.print("  <>                ");
  delay(1500);

  lcd.setCursor(0, 0);lcd.print("****** ****** ******");
  lcd.setCursor(0, 1);lcd.print("|T&RH| | PM | | CO2|");
  lcd.setCursor(0, 2);lcd.print("****** ****** ******");
  lcd.setCursor(0, 3);lcd.print("  <>                ");
  delay(1500);

  lcd.setCursor(0, 0);lcd.print("****** ****** ******");
  lcd.setCursor(0, 1);lcd.print("|TIME| |T&RH| | PM |");
  lcd.setCursor(0, 2);lcd.print("****** ****** ******");
  lcd.setCursor(0, 3);lcd.print("  <>                ");
  delay(1500);

  lcd.setCursor(0, 0);lcd.print("****** ****** ******");
  lcd.setCursor(0, 1);lcd.print("|AUTO| | ON | | OFF|");
  lcd.setCursor(0, 2);lcd.print("****** ****** ******");
  lcd.setCursor(0, 3);lcd.print("  <>                ");
  delay(1500);

  lcd.setCursor(0, 0);lcd.print("****** ****** ******");
  lcd.setCursor(0, 1);lcd.print("|AUTO| | ON | | OFF|");
  lcd.setCursor(0, 2);lcd.print("****** ****** ******");
  lcd.setCursor(0, 3);lcd.print("         <>         ");
  delay(1500);

  lcd.setCursor(0, 0);lcd.print("****** ****** ******");
  lcd.setCursor(0, 1);lcd.print("|AUTO| | ON | | OFF|");
  lcd.setCursor(0, 2);lcd.print("****** ****** ******");
  lcd.setCursor(0, 3);lcd.print("                <>  ");
  delay(1500);
}

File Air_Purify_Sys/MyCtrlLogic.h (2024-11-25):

// Including Encoder and Home Button display reading and judgement, and programmed stabilisation.
// And the relationship of device mode to Encoder Rotate, Encoder Pressed, Home Button Pressed - ‘modeLogic’.

// Function for the Logic of DISPLAYMODE which is also represent the way machine working
void modeLogic(){
  switch (DISPLAYMODE){
    case 0:
      if (EncoderRotate == 0) DISPLAYMODE = 1;
      else if (EncoderRotate == 1) DISPLAYMODE = 1;
      if (buttonPressed) DISPLAYMODE = 1;
      if (homebuttonPressed) DISPLAYMODE = 1;
      break;
    case 1:
      if (EncoderRotate == 0) DISPLAYMODE = 2;
      else if (EncoderRotate == 1) DISPLAYMODE = 1;
      if (buttonPressed) DISPLAYMODE = 13;
      if (homebuttonPressed) DISPLAYMODE = 1;
      break;
    case 2:
      if (EncoderRotate == 0) DISPLAYMODE = 3;
      else if (EncoderRotate == 1) DISPLAYMODE = 1;
      if (buttonPressed) DISPLAYMODE = 14;
      if (homebuttonPressed) DISPLAYMODE = 1;
      break;
    case 3:
      if (EncoderRotate == 0) DISPLAYMODE = 6;
      else if (EncoderRotate == 1) DISPLAYMODE = 2;
      if (buttonPressed) DISPLAYMODE = 15;
      if (homebuttonPressed) DISPLAYMODE = 1;
      break;
    case 4:
      if (EncoderRotate == 0) DISPLAYMODE = 5;
      else if (EncoderRotate == 1) DISPLAYMODE = 1;
      if (buttonPressed) DISPLAYMODE = 14;
      if (homebuttonPressed) DISPLAYMODE = 1;
      break;
    case 5:
      if (EncoderRotate == 0) DISPLAYMODE = 6;
      else if (EncoderRotate == 1) DISPLAYMODE = 4;
      if (buttonPressed) DISPLAYMODE = 15;
      if (homebuttonPressed) DISPLAYMODE = 1;
      break;
    case 6:
      if (EncoderRotate == 0) DISPLAYMODE = 9;
      else if (EncoderRotate == 1) DISPLAYMODE = 5;
      if (buttonPressed) DISPLAYMODE = 16;
      if (homebuttonPressed) DISPLAYMODE = 1;
      break;
    case 7:
      if (EncoderRotate == 0) DISPLAYMODE = 8;
      else if (EncoderRotate == 1) DISPLAYMODE = 4;
      if (buttonPressed) DISPLAYMODE = 15;
      if (homebuttonPressed) DISPLAYMODE = 1;
      break;
    case 8:
      if (EncoderRotate == 0) DISPLAYMODE = 9;
      else if (EncoderRotate == 1) DISPLAYMODE = 7;
      if (buttonPressed) DISPLAYMODE = 16;
      if (homebuttonPressed) DISPLAYMODE = 1;
      break;
    case 9:
      if (EncoderRotate == 0) DISPLAYMODE = 9;
      else if (EncoderRotate == 1) DISPLAYMODE = 8;
      if (buttonPressed) DISPLAYMODE = 10;
      if (homebuttonPressed) DISPLAYMODE = 1;
      break;
    case 10:
      if (EncoderRotate == 0) DISPLAYMODE = 11;
      else if (EncoderRotate == 1) DISPLAYMODE = 10;
      if (homebuttonPressed) DISPLAYMODE = 1;
      break;
    case 11:
      if (EncoderRotate == 0) DISPLAYMODE = 12;
      else if (EncoderRotate == 1) DISPLAYMODE = 10;
      if (homebuttonPressed) DISPLAYMODE = 1;
      break;
    case 12:
      if (EncoderRotate == 0) DISPLAYMODE = 12;
      else if (EncoderRotate == 1) DISPLAYMODE = 11;
      if (homebuttonPressed) DISPLAYMODE = 1;
      break;
    case 13:
      if (homebuttonPressed) DISPLAYMODE = 1;
      break;
    case 14:
      if (homebuttonPressed) DISPLAYMODE = 1;
      break;
    case 15:
      if (homebuttonPressed) DISPLAYMODE = 1;
      break;
    case 16:
      if (homebuttonPressed) DISPLAYMODE = 1;
      break;
    default:
      break;
  }
}

// This thread has an execution period of 1ms, so you can't assign computation tasks to this function.
void encoderThread() {
  int currentStateA = digitalRead(encoderPinA);
  int currentStateB = digitalRead(encoderPinB);

  // Detect rotation, Serial back, change LCD mode
  if (lastEncoderStateA == LOW && currentStateA == HIGH) {
    if (currentStateB == LOW) {// turn left
      encoderPosition--;
      // EncoderRotate = 1;
      // Serial.println("Rotated Left");
    } 
    else {// turn right
      encoderPosition++;
      // EncoderRotate = 0;
      // Serial.println("Rotated Right");
    }
    //modeLogic(); // Change the LCD mode according to the direction of rotation information obtained.
  }

  // refresh the state
  lastEncoderStateA = currentStateA;
  lastEncoderStateB = currentStateB;
  
}

// Accumulate the encoder readings over a period of 10ms to get the result of a left or right turn, and perform the calculation task ‘modeLogic()’.
void CheckEncoderThread(){
  encodercount--;
  if (encodercount<=0){
    encodercount = CONSTENCODERCOUNT;
    if (encoderPosition < 0){
      EncoderRotate = 1;
      Serial.println("Rotated Left");
      modeLogic();
    }
    if (encoderPosition > 0){
      EncoderRotate = 0;
      Serial.println("Rotated Right");
      modeLogic();
    }

    // Renormalise encoderPosition to 0
    encoderPosition = 0;
    // Eliminate direction-of-rotation judgements
    EncoderRotate = 11451;
  }
}

void buttonThread() {
  int currentButtonState = digitalRead(encoderPinBtn);

  // De-jittering detection
  if (currentButtonState != lastButtonState) {
    ButtonlastDebounceTime = millis();
  }

  if ((millis() - ButtonlastDebounceTime) > DEBOUNCE_TIME) {
    // Button state change detection
    if (currentButtonState == LOW && !buttonPressed) {
      buttonPressed = true;
      Serial.println("Button Pressed");
      modeLogic();
    } 
    else if (currentButtonState == HIGH && buttonPressed) {
      buttonPressed = false;
      Serial.println("Button Released");
    }
  }

  // Update button status
  lastButtonState = currentButtonState;
}

void homeBtnThread() {
  int currentHomeBtnState = digitalRead(homeBtnPin);

  // De-jittering detection
  if (currentHomeBtnState != homelastButtonState) {
    homeBtnlastDebounceTime = millis();
  }

  if ((millis() - homeBtnlastDebounceTime) > DEBOUNCE_TIME) {
    // Button state change detection
    if (currentHomeBtnState == HIGH && !homebuttonPressed) {
      homebuttonPressed = true;
      Serial.println("Home Button Pressed");
      modeLogic();
    } 
    else if (currentHomeBtnState == LOW && homebuttonPressed) {
      homebuttonPressed = false;
      Serial.println("Home Button Released");
    }
  }

  // Update button status
  homelastButtonState = currentHomeBtnState;
}

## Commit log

2024-11-19 update
    EC11 and RITOS frame
2024-11-20 In "Air_Purify_Sys" v0.1, encoder accuracy suffered from "modeLogic()" delays, addressed in RITOS_Encoder_v2 with 10ms detection intervals.
    "Air_Purify_Sys" is the main folder for the project, the LCD could be interact with the encoder in v0.1. However, the detection ability of the encoder was not that good, and it is supposed caused by 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
2024-11-20 v0.2
    v0.2 solve the LCD and encoder issues
    [Air_Purify_Sys.ino, MyEncoder.h]
2024-11-21 v0.3
    Add the example of ESP8266 get the time for London and China, add a button in the MyConfig.h. The Structure of the project was changed. Wifi was OK to connect, but if use the NTP, the ESP8266, stack 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
2024-11-22 v0.4 update
    The UI is fully functional, and the threads and headers have been reclassified so that the Get Time and Get Sensor threads are considered to be Get Data threads, and the LCD and Fan threads are consi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
2024-11-23 v4 time display fixed
    The display of world time on LCD is add to the project
    [Air_Purify_Sys.ino]
2024-11-23 v0.5 update for better threads
    Change the values in "MyConfig.h" to modify the frequency for every threads, except the 1kHz threads
2024-11-23 v0.5 update for fan, homebtn and ccs811
    Fixed the logic bug for fan opperation;
    Changed the pin for homebtn and ccs811;
    Feature: The fan logic is right, homebtn works properly, and ccs811 works properly
    [Air_Purify_Sys.ino, I2C_address_search.ino, MyConfig.h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]
2024-11-24 v0.6 update
    The function of PMS7003 is fixed and good to use!
    [Air_Purify_Sys.ino, MyConfig.h, MySensors.h]
2024-11-25 v0.6 update for SHT30
    Most functions work fine, but the fan is on by default so the relay outputs need to be replaced. As well as needing to change the Auto mode logic.
    [Air_Purify_Sys.ino, MyConfig.h, MySensors.h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]
2024-11-26 v0.6 update
    Fixed the bug the FAN is on by default even the MCU is closed. Also updated the Readme
2024-11-26 v0.6 update for fan auto mode and README
    v0.6 update for fan auto mode and README
    [Pure-Breath-propotype-v1.0.f3d]
2024-11-26 v0.6 update
    Fixed the mistakes in Blue print, also updated the README
    [Pure-Breath-propotype-v1.0.f3d, Pure-Breath-v29.f3d]
